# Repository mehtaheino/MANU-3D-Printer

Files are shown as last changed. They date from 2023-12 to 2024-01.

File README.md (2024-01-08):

# Welcome to the MANU 3D Printer Documentation

This page provides comprehensive documentation for the MANU 3D Printer, an extrusion-based FFF printer. The printer was manufactured between 2020 and 2021.

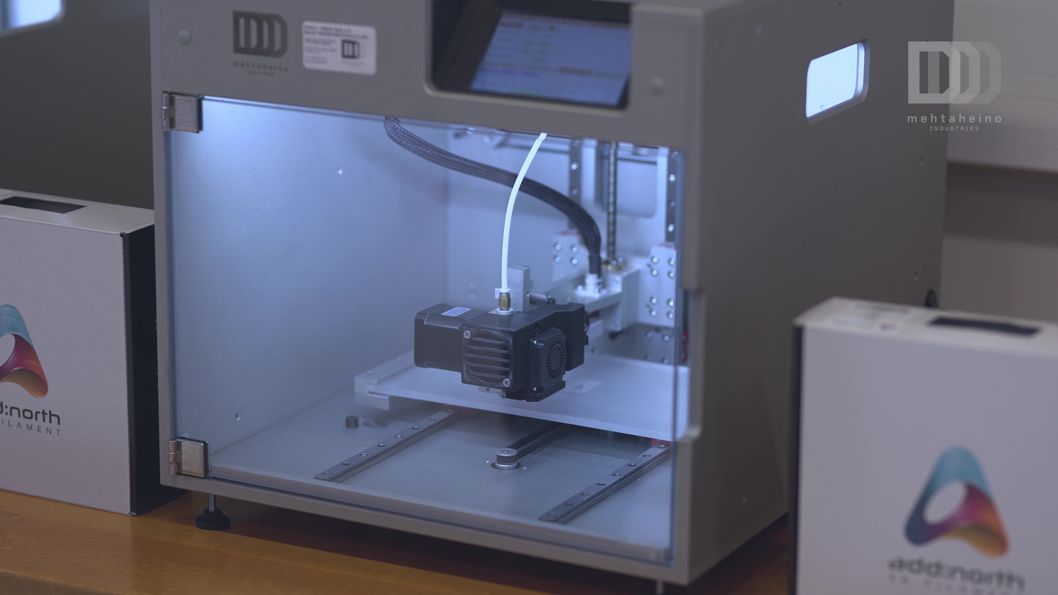
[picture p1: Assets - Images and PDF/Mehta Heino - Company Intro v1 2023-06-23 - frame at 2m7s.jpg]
MANU 3D Printer


## Technical Support

While our operations have been discontinued, we remain committed to providing our valued customers with technical support. 

Please feel free to reach out if you require assistance with our products or services.

## Assistance Options:

* Printer Documentation: https://github.com/mehtaheino/MANU-3D-Printer/wiki
* Discussion (Q&A) on GitHub: https://github.com/orgs/mehtaheino/discussions
* Previous Wiki Page link (Printer Documentation): https://www.wiki.mehtaheino.com/

## Home - GitHub Wiki Page / Documentation Page
https://github.com/mehtaheino/MANU-3D-Printer/wiki

## MANU 3D Printer, an extrusion-based FFF printer

* [Step 1. Unboxing and getting the printer ready](https://github.com/mehtaheino/MANU-3D-Printer/wiki/Step-1.-Unboxing-and-getting-the-printer-ready)
* [Step 2. Connecting to Wi‐Fi on MANU 3D Printer](https://github.com/mehtaheino/MANU-3D-Printer/wiki/Step-2.-Connecting-to-Wi%E2%80%90Fi-on-MANU-3D-Printer)
* [Step 3: Simplify3D Setup for MANU 3D Printer 1.0](https://github.com/mehtaheino/MANU-3D-Printer/wiki/Step-3:-Simplify3D-Setup-for-MANU-3D-Printer-1.0)
* [Step 4. First print on MANU Easy](https://github.com/mehtaheino/MANU-3D-Printer/wiki/Step-4.-First-print-on-MANU-Easy)
* [Step 5. Material selection guide](https://github.com/mehtaheino/MANU-3D-Printer/wiki/Step-5.-Material-selection-guide)
* [Step 6. Slicing best practices Generating Gcode](https://github.com/mehtaheino/MANU-3D-Printer/wiki/Step-6.-Slicing-best-practices---Generating-Gcode)
* [Step 7. Extruder advanced guide](https://github.com/mehtaheino/MANU-3D-Printer/wiki/Step-7.-Extruder-advanced-guide)
* [Discussion (Q&A) on GitHub](https://github.com/orgs/mehtaheino/discussions)

---

# Chocolate Printer Documentation
Please refer to the following links for documentation specific to the Chocolate Printer:

## MANU Food 3D Printer, Piston Extrusion-Based Chocolate 3D Printer
* For chocolate Printer: https://github.com/mehtaheino/Chocolate-3D-Printer/wiki
* Discussion (Q&A) on GitHub: https://github.com/orgs/mehtaheino/discussions

<!-- toc -->

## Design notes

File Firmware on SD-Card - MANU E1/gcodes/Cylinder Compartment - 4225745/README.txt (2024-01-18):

Cylinder Compartment by Crwigley on Thingiverse: https://www.thingiverse.com/thing:4225745

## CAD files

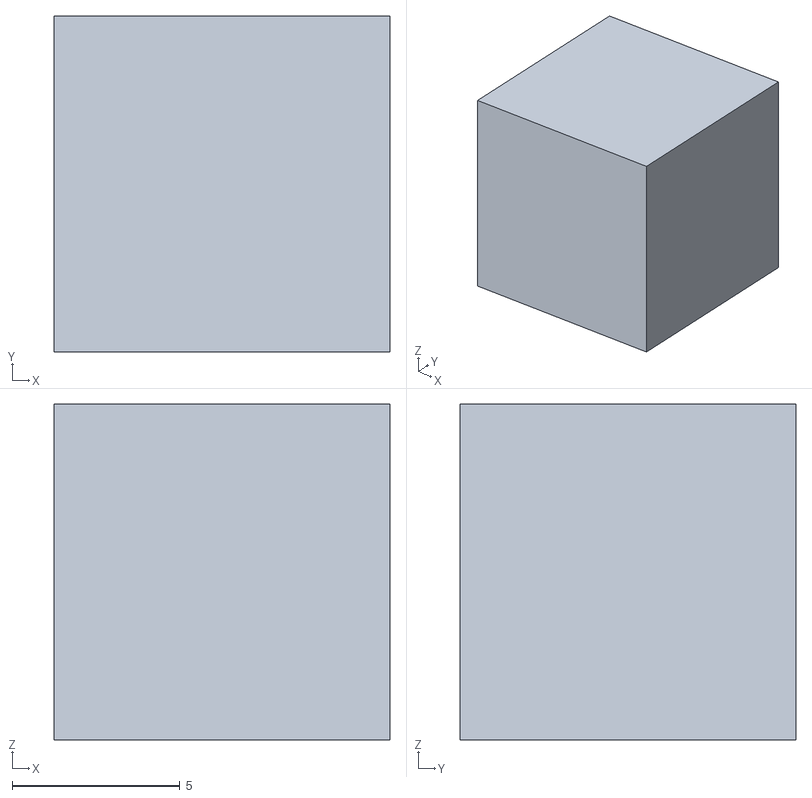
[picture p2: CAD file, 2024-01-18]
Firmware on SD-Card - MANU E1/gcodes/cube - 6370662/files/cube.stl
10.0 x 10.0 x 10.0

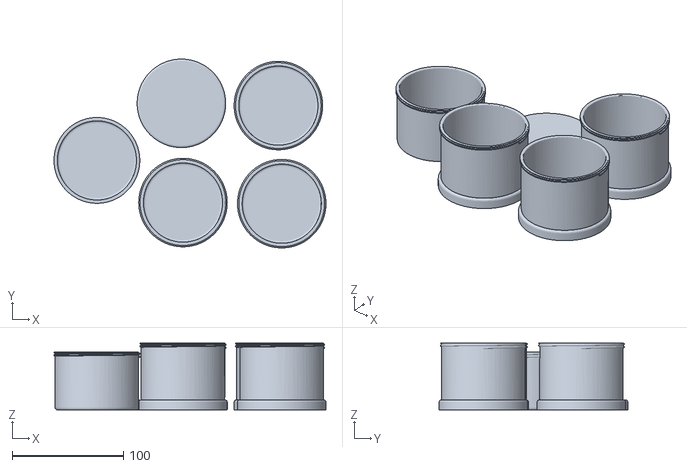
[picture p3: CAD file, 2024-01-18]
Firmware on SD-Card - MANU E1/gcodes/Cylinder Compartment - 4225745/files/Cylinder_Compartments.stl
244.0 x 169.4 x 60.0

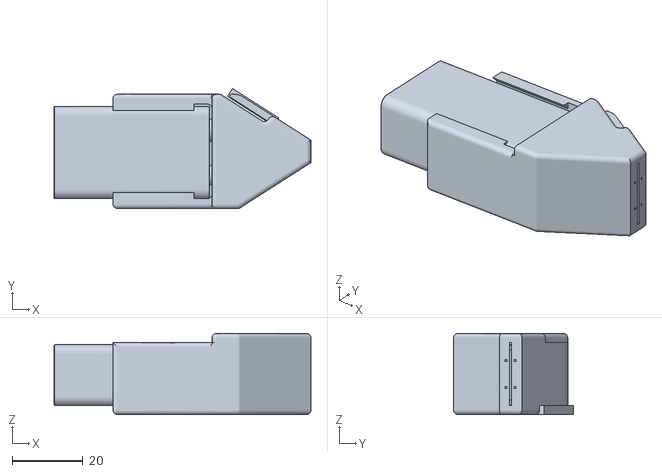
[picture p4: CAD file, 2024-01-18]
Simplify3D Print Settings - MANU E1/Addnorth Koltron G1/ANKG1-1.0.0-E1-S3D 21W30/734602 Thingiverse - Fully_3D_printable_flashlight/734602 Thingiverse - flashlight-assembly .STL
72.5 x 33.9 x 22.9

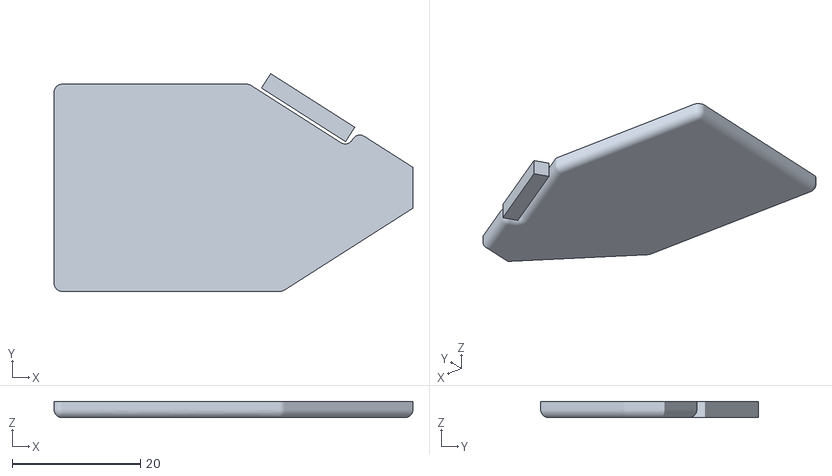
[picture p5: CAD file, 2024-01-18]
Simplify3D Print Settings - MANU E1/Addnorth Koltron G1/ANKG1-1.0.0-E1-S3D 21W30/734602 Thingiverse - Fully_3D_printable_flashlight/734602 Thingiverse - flashlight-base .STL
55.9 x 33.9 x 2.54

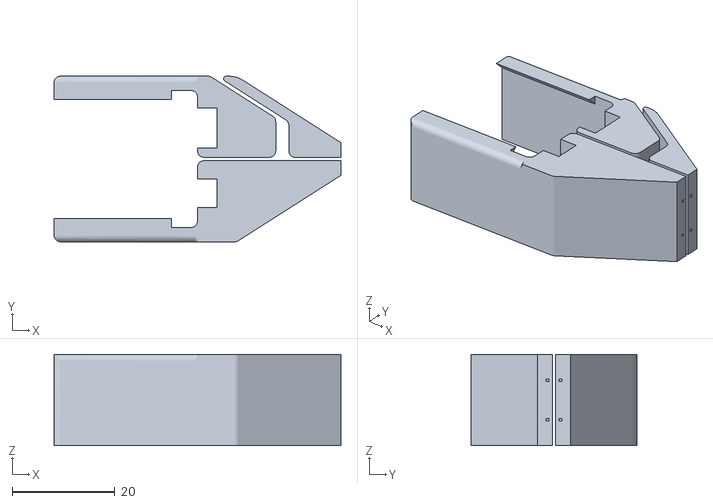
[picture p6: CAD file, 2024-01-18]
Simplify3D Print Settings - MANU E1/Addnorth Koltron G1/ANKG1-1.0.0-E1-S3D 21W30/734602 Thingiverse - Fully_3D_printable_flashlight/734602 Thingiverse - flashlight-conductive .STL
55.9 x 32.3 x 17.8

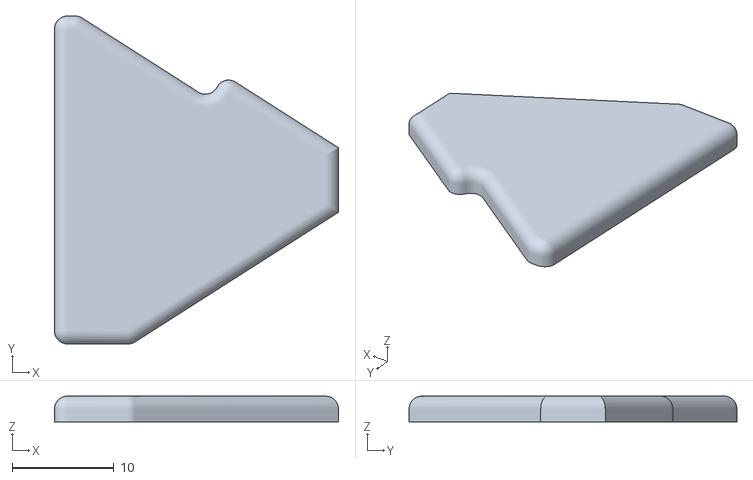
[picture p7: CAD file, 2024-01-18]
Simplify3D Print Settings - MANU E1/Addnorth Koltron G1/ANKG1-1.0.0-E1-S3D 21W30/734602 Thingiverse - Fully_3D_printable_flashlight/734602 Thingiverse - flashlight-top .STL
27.9 x 32.3 x 2.54

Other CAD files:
Firmware on SD-Card - MANU E1/gcodes/cube - 6370662/files/cube.scad

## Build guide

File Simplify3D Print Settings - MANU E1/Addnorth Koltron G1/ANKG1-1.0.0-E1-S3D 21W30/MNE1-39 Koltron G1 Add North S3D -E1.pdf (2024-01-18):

Last Updated on Aug 10, 2021 _______________________________ MNE1-39 Koltron G1 Add North S3D -E1

# Purpose of the document

Developing Simplify3D printing profile for MANU Easy 1.0 for Add North Koltron G1

1
filament.

# Compatibility with MANU Easy 1.0

1. Koltron specifications state that it needs high extrusion temperatures.
2. MANU E1 hasn't been tested with those before but review of electronics and heaters suggest it won't be a problem.
3. Build plate reaction with Koltron has not been tested before.
4. No information about Acrylic plate and Koltron.

# Change log

1. v1.0 - Aug 9, 2021 Petri Heino Started the document and Manabi Poudel Update the document about print settings

2

1 More information can be found here https://addnorth.fi/product/Koltron%20G1/2 Reference document MNE1-39 Internal tests - Koltron G1 Add North -E1 (https://www.dropbox.com/scl/fi/2j95lpe2l2df32r9ue28g/MNE1-39-Internal-tests-Koltron-G1-Add-North-E1.gdoc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)

MEHTA HEINO INDUSTRIES OY
WWW.MEHTAHEINO.COM

v1.0

## TABLE OF CONTENTS

Purpose of the document | 1
Compatibility with MANU Easy 1.0 | 1
Change log | 1
Koltron G1 - Add North’s Materials information | 3
Print settings recommendation from Add North | 3
Guidelines on how to print Koltron G1 on MANU Easy 1.0 | 4
Build Plate | 4
Changes required to print Koltron G1 | 4
Development of print profile | 5
Minimum extrusion temperature | 5
1st layer printing temperature | 5
Printing temperature | 6
At 280 °C with the fan on. | 6
At 290 °C with fan off. | 7
Further Improvement | 7
Microscope image of prints. | 8
Final profile name: | 8
Other observation | 9
Open questions / More testing is required: | 9
Download Simplify3d profile from here | 9
Dropbox Shared Folder | 9

# Koltron G1 - Add North’s Materials information

- Electrically and thermally conductive filament
- Filament with the highest flame-retardant rating
- Chemical resistantAdd North’s Koltron G1 is a very electrically and thermally conductive filament. It’s resistant to a range of chemicals, UV light and high continuous working temperatures, with the highest flame-retardant rating. The versatility is unmatched in polymer additive manufacturing.

The application areas for Koltron G1 are vast, ranging from EMI and RFI (electromagnetic and radio frequency interference) shielding to capacitive sensors, wearable and printed electronics as well as the cooling of electronics. The incorporation of Graphmatech’s unique AROS Graphene also gives the printed parts excellent self-lubricating properties.

## Print settings recommendation from Add North

Temperature | First Layer 280°C, Print Temperature 290°C
Fan speed | - (zero)
Print speed | 15 mm/sec

# Guidelines on how to print Koltron G1 on MANU Easy 1.0

## Build Plate

Acrylic plate A010702

3

# Changes required to print Koltron G1

- The double fan update is needed
- Better arm cooling (no problems of raised temperature)
- The print tests were performed with print cooling fan 0%, and fan speed affects Koltron Layer adhesion drastically.
- Raising the maximum allowed temperature
- M143 Command (https://duet3d.dozuki.com/Wiki/Gcode#Section_M143_Maximum_heater_temperature)
- It is set in config.g
- Change the S value to 300 to support 300

oC.

3 A010702 -

M143 H1 S300 | ;set temperature limit for heater 1 to 300C

# Development of print profile

## Minimum extrusion temperature

Material was tried to extrude at

## 1st layer printing temperature

Manabi Poudel decided not to lower the temperature more than 265

oC because the
material can lose strength.
Temperature °C | Description
1. | 210 °C | Koltron G1 was extruded upto 60mm and then it got stuck. Others observation: Gear has grinded the filament.
2. | 235 °C | Extrusion temperature is too low to flow the materials.
3. | 275 °C | Good material flow was observed at 275°C.
Temperature °C | Description
1. | 268 °C | The printed part was successfully removed from the bed, but part leaves some colour mark at the plate.
2. 270 °C | The printed part comes out from the bed but a small layer is broken from the bed.
3. 272 °C | oC and 272 oC. Material Printed part was hard to remove with 275 stuck too much to the bed.
4. 275°C

## Printing temperature

Part was printed at 280

oC, 290

oC and 295

oC

At 280 °C with the fan on.

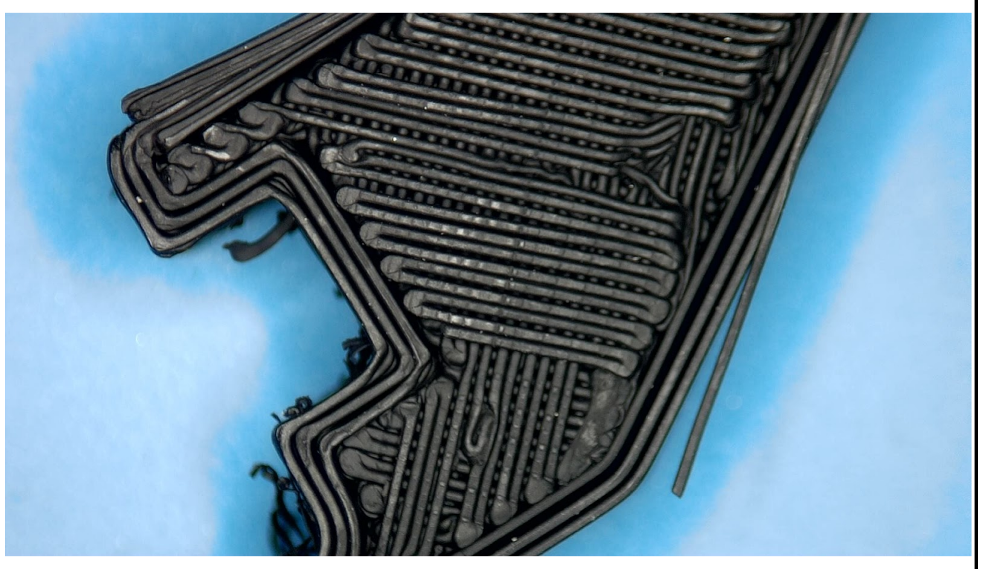
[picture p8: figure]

Koltron_test_low temperature_with_fan_2 (bottom view)

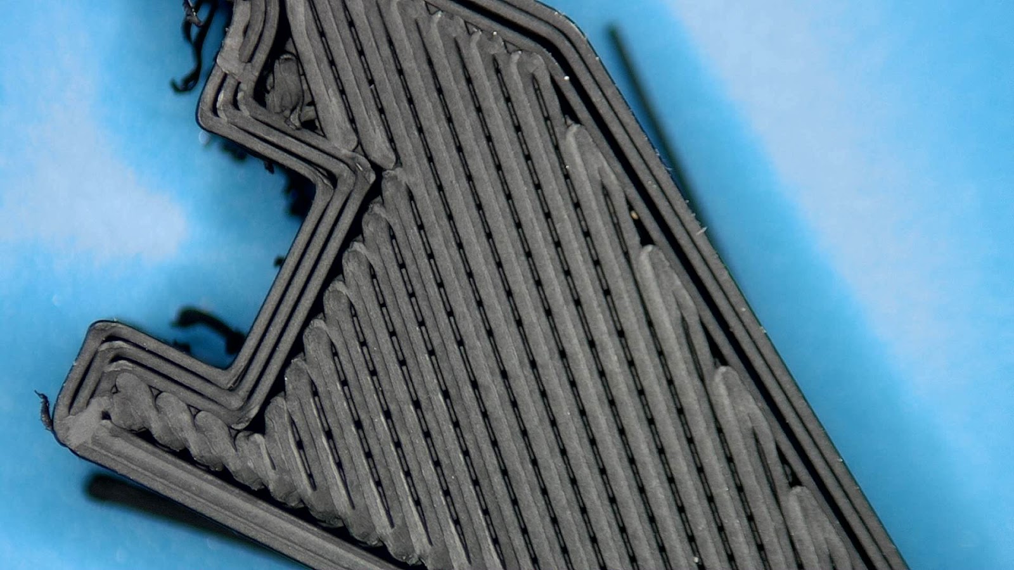
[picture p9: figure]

Koltron_test_low temperature_with_fan_1 (top view)

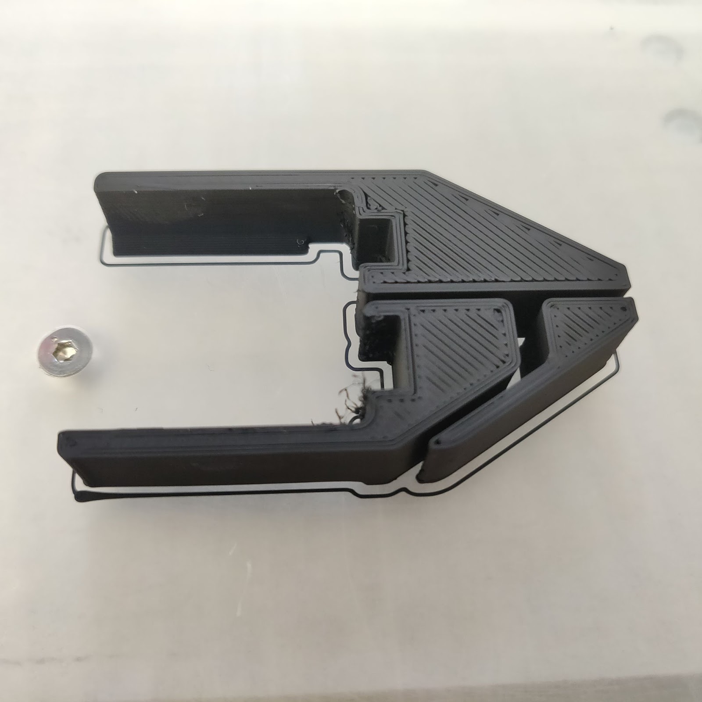
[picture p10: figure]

At 280

oC with a fan 100% part was very weak and breaking apart.

At 290 °C with fan off.

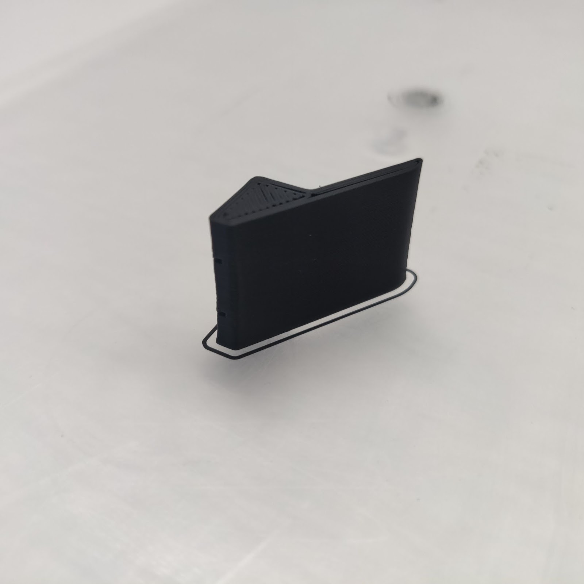
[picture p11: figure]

## Further Improvement

Theory is that gradual increase in temperature would make for better layer adhesion.

Temperature set as

4 1st layer printing temperature The printed part was successfully removed from the bed, but part leaves some colour mark at the plate.

At 290

oC part with fan off print was much better and stronger.

Layer | Temperature
1st Layer | 268°C
| 4
2nd Layer | 280°C
3rd Layer | 290°C
4th Layer | 295°C

Microscope image of prints.

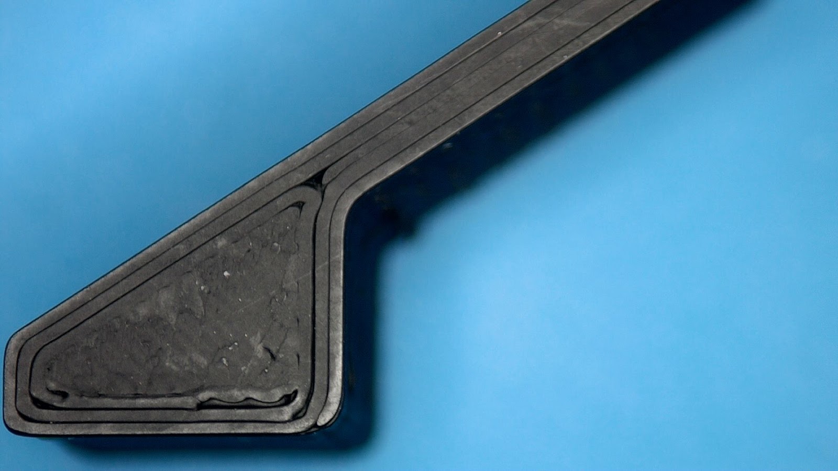
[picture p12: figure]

Koltron_g1_3 (bottom view)

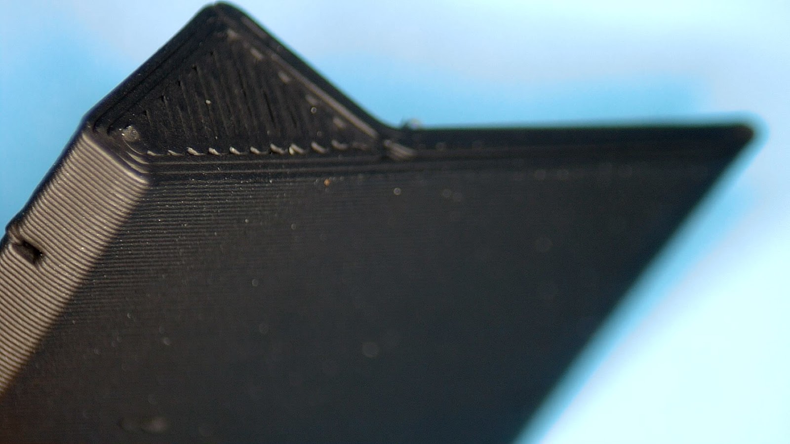
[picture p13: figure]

Koltron_g1_2 (top view)

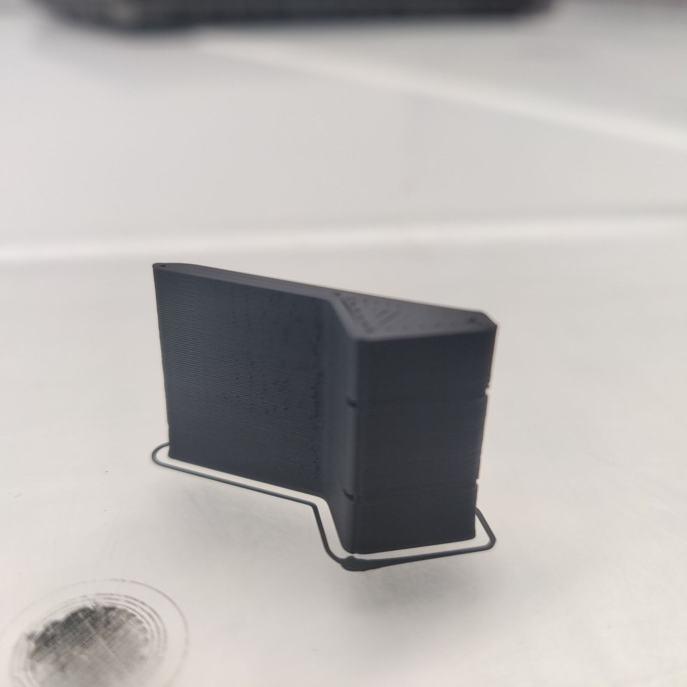
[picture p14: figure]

For more strong adhesive infill overlap increased to 20% and print temperature 295

oC

### Final profile name:

ANKG1 1.0.0 E1 S3D.fff

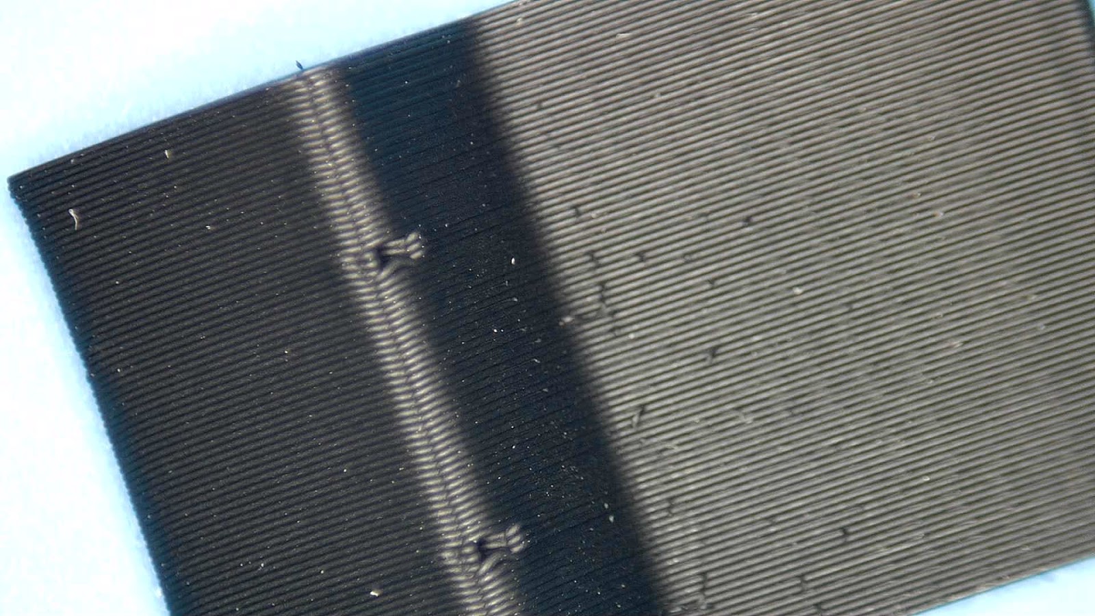
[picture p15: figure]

Koltron_g1_1 (side view)

# Other observation

Tested 1st layer print with PC plate at 280 °C, Kaltron makes no connection with the PC plate at 280, but makes a good chemical connection to Acrylic.

# Open questions / More testing is required:

1. Support test
2. Big part printing test
3. Thermistor insulation specification sheet recommends that time used in 300 degrees is max 4 hours. Long term usage at near 300deg should be tested more.
4. To maintain the temperature of the hotend, a new hotend shield may be needed. New hotend shield is in the production process.

# Download Simplify3d profile from here

# — Thank you! —

## Dropbox Shared Folder

## Addnorth Koltron G1 e1 -p

https://www.dropbox.com/sh/psvb11fj6qi11oo/AABAEyeM-WMc8BTigMrHCJb-a?dl=0 (https://www.dropbox.com/sh/psvb11fj6qi11oo/AABAEyeM-WMc8BTigMrHCJb-a?dl=0)

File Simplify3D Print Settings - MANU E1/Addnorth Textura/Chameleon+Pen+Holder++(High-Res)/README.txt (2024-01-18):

Chameleon Pen Holder  (High-Res) by PRIma on Thingiverse: https://www.thingiverse.com/thing:4921173

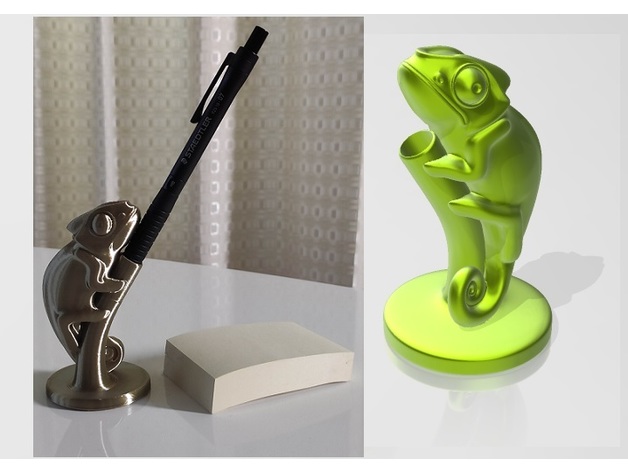
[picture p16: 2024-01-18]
Simplify3D Print Settings - MANU E1/Addnorth Textura/Chameleon+Pen+Holder++(High-Res)/images/Camaleon_Penholder_smooth_byPRIma2.jpg

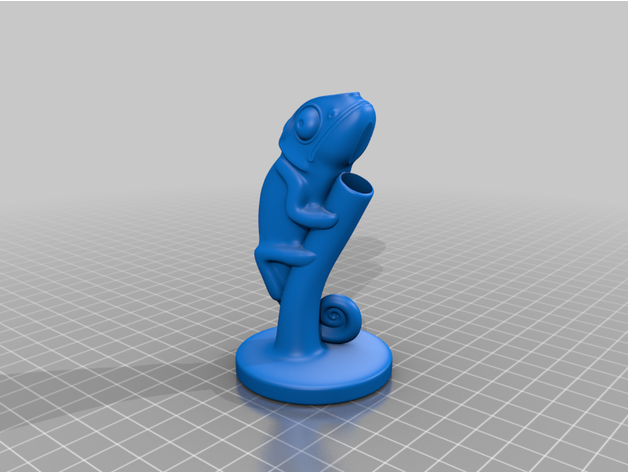
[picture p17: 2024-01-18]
Simplify3D Print Settings - MANU E1/Addnorth Textura/Chameleon+Pen+Holder++(High-Res)/images/Camaleon_Penholder_smooth_byPRIma.png

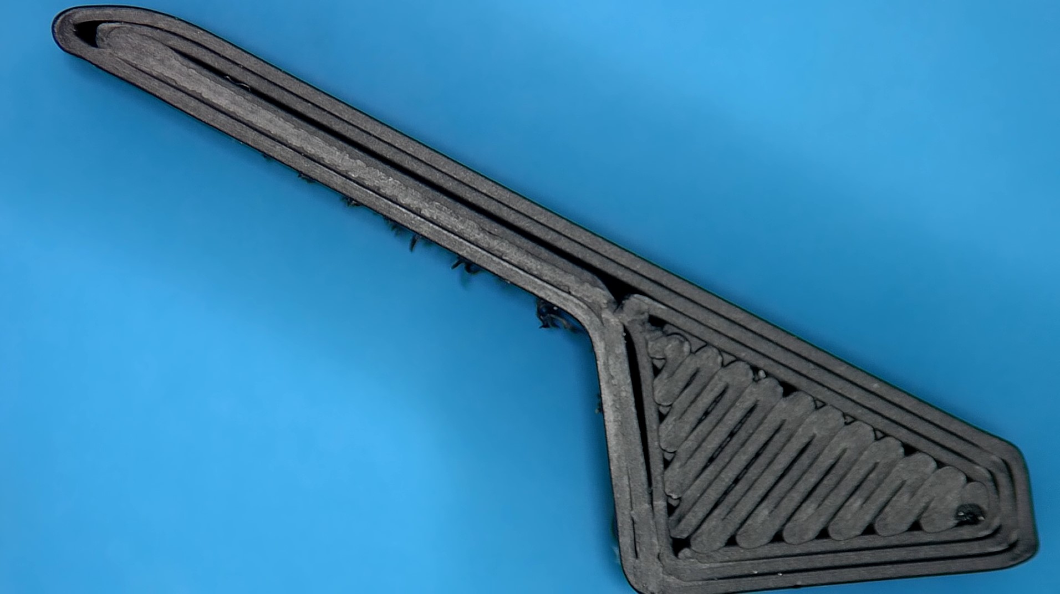
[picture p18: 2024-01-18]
Simplify3D Print Settings - MANU E1/Addnorth Koltron G1/ANKG1-1.0.0-E1-S3D 21W30/Print’s Photos from ANKG1-0.1.0-E1-S3D profile 2021-07-29/WIN_20210730_11_25_43_Pro ANKG1-E1-S3D .jpg

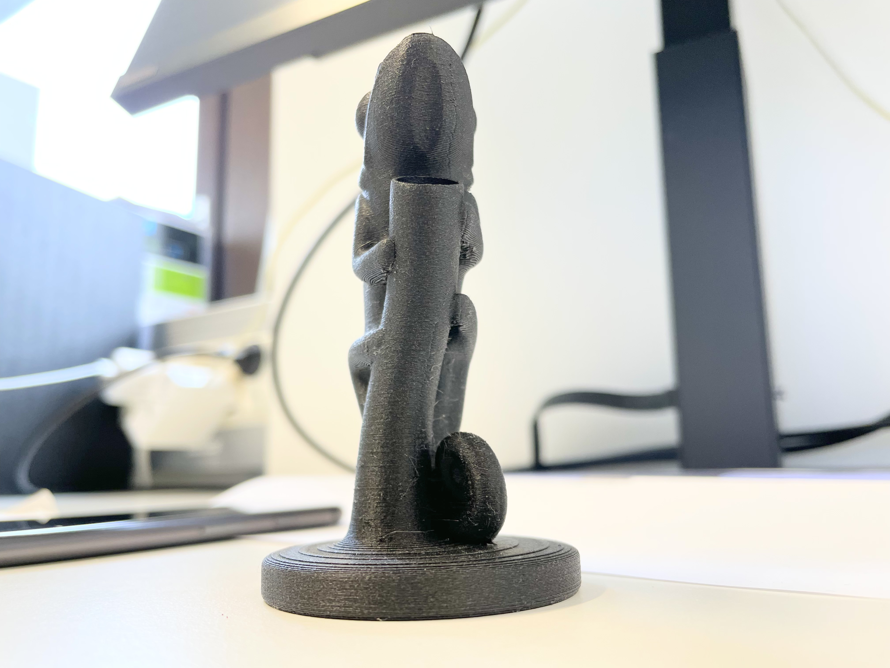
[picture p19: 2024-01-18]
Simplify3D Print Settings - MANU E1/Addnorth Textura/P100 Textura Addnorth/Textura P100 - IMG_0650.jpeg

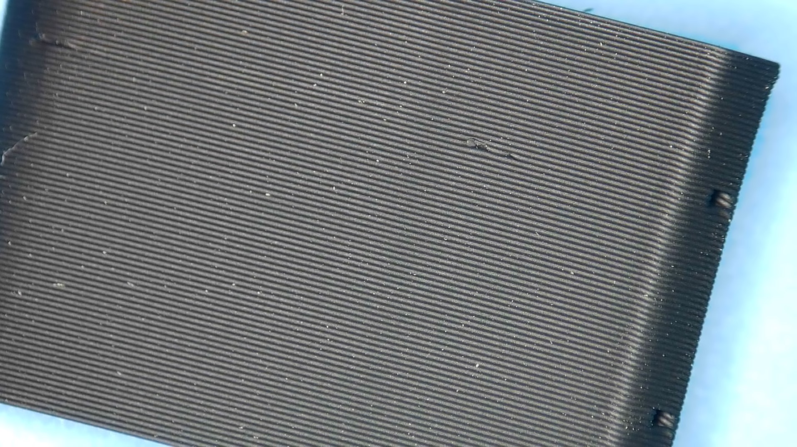
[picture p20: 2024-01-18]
Simplify3D Print Settings - MANU E1/Addnorth Koltron G1/ANKG1-1.0.0-E1-S3D 21W30/Print’s Photos from ANKG1-0.1.0-E1-S3D profile 2021-07-29/WIN_20210730_11_34_31_Pro ANKG1-E1-S3D .jpg

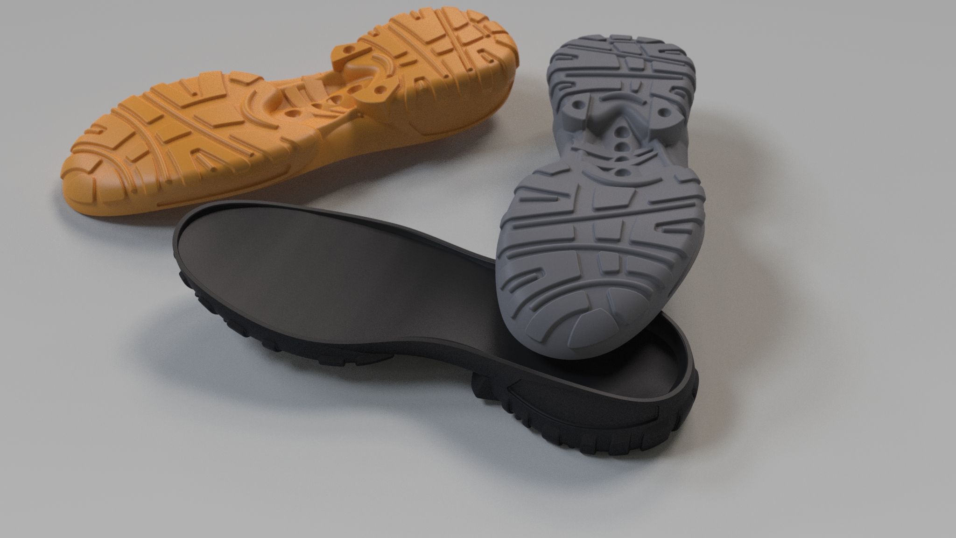
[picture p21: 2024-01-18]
Simplify3D Print Settings - MANU E1/Polymaker TPU-95/P87 Polymaker TPU-95/sports-2 from Grabcad 21W34/sports3.jpeg

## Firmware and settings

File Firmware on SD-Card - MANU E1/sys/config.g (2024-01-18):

; Configuration file for Duet WiFi (firmware version 3) 
; executed by the firmware on start-up 
 
; General preferences 
G90                                            ; send absolute coordinates... 
M83                                            ; ...but relative extruder moves 
M550 P"MANU 3DPrinter [mehtaheino.com]"       ; set printer name, Serial 
 
; Network 
M552 S1                                        ; enable network 
M586 P0 S1                                     ; enable HTTP 
M586 P1 S0                                     ; disable FTP 
M586 P2 S0                                     ; disable Telnet 

; Drives 
; Note direction of motors, may be different according to revision of wiring. 
; Confirm production series with serial number. 
M569 P0 S1 
M569 P1 S0 
M569 P2 S0 
M569 P3 S1 
M584 X0 Y1 Z2 E3 
M350 X16 Y16 Z16 I1 
M350 E256 I0 
M92 X80.00 Y80.00 Z400.0 E2210.000 
M906 X2000 Y2000 Z1400 E1400 I30 ; PH 1.10.23 test raising it from 1100 to 1400
M84 S30 

;Kinematics 
M566 X300 Y300 Z600 E3000 
M566 P1 
M203 X6000 Y6000 Z3600 E6000 
M201 X2000 Y2000 Z200 E9000 
M204 P600 T600 

; Axis Limits 
M208 X0 Y0 Z-1 S1                               ; set axis minima 
M208 X256 Y165 Z210 S0                       ; set axis maxima 
;M208 X256 Y165 Z202.85 S0                       ; PH BLTOUCH TEST: Nozzle touches bed at Z0.15. At Z203 it was already working. Adjusting it to Z202.85 for more accuracy


; Endstops 
M574 Z0 P"nil" ;reset z preconfigurations TEST
M574 X1 S1 P"xstop"                             ; configure active-high endstop for low end on X via pin null 
M574 Y1 S1 P"ystop"                             ; configure active-high endstop for low end on Y via pin null 
M574 Z2 S1 P"zstop"                                    ; configure Z-probe endstop for high end on Z 

; Z-Probe 
M950 S0 C"exp.heater3" 
M558 P9 C"^exp.e2stop" H3 F120 T6000 ;Bltouch setup 
G31 P25 X0 Y40 Z2.00 ;Measured value of bltouch is Z1.94 (2.10.23) but layer measures 0.1mm too high. Forcing Z closer 0.06, to Z2.00
 
M557 X10:240 Y40:140 P10:6 

;G29 S1 ;Enable mesh compensation with a level parameter of 1 by SM 2023-01-01 1936

; Heaters 
M308 S1 P"e0temp" Y"thermistor" T100000 B5020 C1.09016e-7 ; configure sensor 1 as thermistor on pin e0temp 
M950 H1 C"e0heat" T1                           ; create nozzle heater output on e0heat and map it to sensor 1 
M307 H1 B0 S1.00                               ; disable bang-bang mode for heater  and set PWM limit 
M143 H1 S300                                   ; set temperature limit for heater 1 to 300C 

; Fans 
M950 F0 C"exp.heater4" Q250 ;12V Fan Extension - Print cooling fan 
M106 P0 S0 H-1 ; Set fan 0 value. 
 
M950 F1 C"exp.heater5" Q250 
M106 P1 T40 H1 
 
M950 F2 C"fan2" Q250 
M106 P2 T40 H1 
;Other fan connectors: Always on: LED 24V. 

; Tools 
M563 P0 D0 H1 F0                               ; define tool 0 
G10 P0 X0 Y0 Z0                                ; set tool 0 axis offsets 
G10 P0 R0 S0                                   ; set initial tool 0 active and standby temperatures to 0C 

; Miscellaneous 
M575 P1 S1 B57600                              ; enable support for PanelDue 
M501 

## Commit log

2024-01-18 Simplify3D Profile uploaded
    Simplify3D Profile for MANU E1 has been uploaded to GitHub Repo
    [734602 Thingiverse - flashlight-assembly e1 -p.STL, 734602 Thingiverse - flashlight-base e1 -p.STL, 734602 Thingiverse - flashlight-conductive e1 -p.STL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]
2024-01-18 Simplify3d Profile has been arranged.
    [734602 Thingiverse - flashlight-assembly e1 -p.STL, 734602 Thingiverse - flashlight-base e1 -p.STL, 734602 Thingiverse - flashlight-conductive e1 -p.STL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]
2024-01-18 Files has been rearranged.
    [734602 Thingiverse - flashlight-assembly e1 -p.STL, 734602 Thingiverse - flashlight-base e1 -p.STL, 734602 Thingiverse - flashlight-conductive e1 -p.STL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]
2024-01-18 Files has been rearranged
    [734602 Thingiverse - flashlight-assembly e1 -p.STL, 734602 Thingiverse - flashlight-base e1 -p.STL, 734602 Thingiverse - flashlight-conductive e1 -p.STL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]
2024-01-18 Manu E1 - Firmware has been uploaded
    [734602 Thingiverse - flashlight-assembly e1 -p.STL, 734602 Thingiverse - flashlight-base e1 -p.STL, 734602 Thingiverse - flashlight-conductive e1 -p.STL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]
2024-01-18 e1 -p extension has been removed.
    [734602 Thingiverse - flashlight-assembly .STL, 734602 Thingiverse - flashlight-base .STL, 734602 Thingiverse - flashlight-conductive .STL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]
